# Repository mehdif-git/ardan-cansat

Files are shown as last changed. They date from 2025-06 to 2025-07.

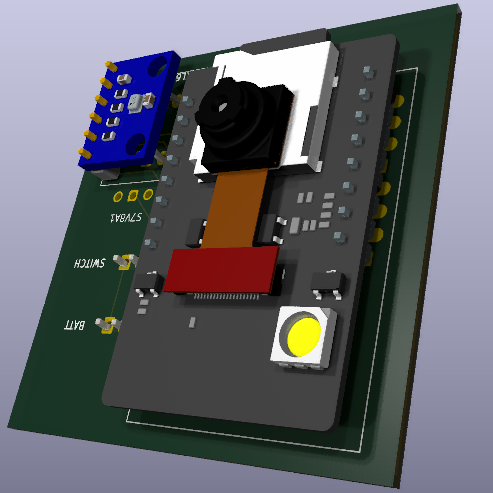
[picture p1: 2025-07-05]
Elec_Ardan/Pictures/Elec_Ardan.png

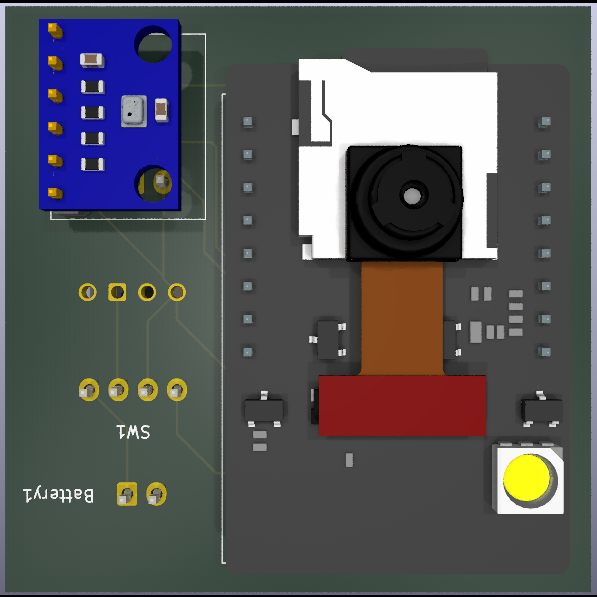
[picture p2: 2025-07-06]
Elec_Ardan/Pictures/Elec_Ardan_Front.png

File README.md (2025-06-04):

## SCALAR-VI CANSAT *Ardan*

## Description
Code and schematics of the cansat aboard SCALAR-VI made with students of the Jules Verne middleschool in Carcassone, FR.

## Installation
The ‘RadioHead’ library used to manage the LoRaWAN depends on “stdatomic”, we need to change the source code of ‘RadioHead’ to source the correct implementation for Arduino vs. ESP.

## Contributing
This work is common to the Supaero Space Section's Scalar project. Any project member is allowed to contribute.

## Authors and acknowledgment
Electronics has been made with the help of F. Topeza and C. Mopin-Rauschkolb.
CAD has been done entierly by D. Bessede

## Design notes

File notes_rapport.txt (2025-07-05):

\section{Électronique}

Liste des hacks faits :
\begin{itemize}
  \item Le connecteur de la batterie avait une polarisation opposée à celui du
    chargeur -> Utilisation de câbles Dupont pour résoudre le problème (ça marche,
    photos du problème, et de la tension au multimètre).
  \item La bibliothèque "RadioHead" utilisée pour gérer le LoRaWAN dépend de
    "stdatomic", on doit changer le code source de "RadioHead" pour en sourcer
    l'implémentation correcte pour Arduino  vs. ESP (montrer le code).
\begin{itemize}

\begin{figure}[H]
    \centering
    \frame{\includegraphics[width=0.8\textwidth]{images/Electronique/schematic.png}}
    \caption{Schéma de l'électronique à bord du cansat}
    \label{fig:enter-label}
\end{figure}

\begin{wrapfigure}{l}{0.25\textwidth}
    \frame{\includegraphics[width=0.95\linewidth]{images/Electronique/Test_elec_1.jpg}} 
    \caption{Tests électroniques}
    \label{fig:wrapfig}
\end{wrapfigure}

\noindent L'alimentation du cansat est assurée par une batterie LiPo d'une cellule de capacité de 550mAh. La tension nominale de la batterie Li-Po est de 3,7V. Pour assurer une sortie en 3,3V pour la majorité de l'électronique, un convertisseur \textit{buck-boost} (S7V8A) est utilisé. Ce dernier prends en entrée une tension entre 2,5 et 8V, largement au-delà de l'interval de 3 à 4,2V de la tension de la batterie.\\

\noindent Le buzzer est le seul composant électronique ne prenant pas en entrée une tension de 3,3V, l'architecture utilise un convertisseur \textit{boost} (XL6009) permettant d'élever la tension de 3,3V en 12V. Une diode (1N4007) est utilisée pour bloquer le retour de l'inductance du buzzer.\\

\noindent Le BMP280 communique avec l'ESP32 en I²C et le module LoRaWAN en UART.
Un pin de l'ESP32 est utilisé pour contrôler l'allumage du buzzer à travers un transistor (BC337-25) relié à une résistance pull-down de 100$k\Ohm$ pour assurer un état \textit{LOW} en général. Le buzzer est activé au moment de l'atterrissage du cansat.\\

\noindent 

\noindent Le courant maximal passant par le dispositif est de 245 milliampères :
\begin{itemize}
    \item  ESP32-CAM en prise d'image : pic de consommation à 200mA@3,3V
    \item  Consommation négligeable du BMP280 (2,7µA)
    \item  Module LoRa : 30mA@3,3V en émission
    \item  Buzzer : 15mA@12V en utilisation
\end{itemize}

La batterie permet donc un fonctionnement durant 2 heures.

\begin{figure}[!ht]
    \centering
    \begin{minipage}{0.3\textwidth}
        \centering
        \includegraphics[width=\textwidth]{images/Composants/BMP280.jpg}
        \caption{Module BMP280}
        \label{fig:bmp280}
    \end{minipage}
    \hfill
    \begin{minipage}{0.3\textwidth}
        \centering
        \includegraphics[width=\textwidth]{images/Composants/ESP32CAM.png}
        \caption{ESP32CAM}
        \label{fig:esp32cam}
    \end{minipage}
    \hfill
    \begin{minipage}{0.3\textwidth}
        \centering
        \includegraphics[width=\textwidth]{images/Composants/S7V8A.jpg}
        \caption{Module S7V8A}
        \label{fig:s7v8a}
    \end{minipage}

    \vspace{0.5cm} % Espace entre les deux rangées

    \begin{minipage}{0.3\textwidth}
        \centering
        \includegraphics[width=\textwidth]{images/Composants/DSN6009.jpg}
        \caption{XL6009}
        \label{fig:xl6009}
    \end{minipage}
    \hfill
    \begin{minipage}{0.3\textwidth}
        \centering
        \includegraphics[width=\textwidth]{images/Composants/LoRa WAN.png}
        \caption{Module LoRaWAN}
        \label{fig:lorawan}
    \end{minipage}
\end{figure}
\clearpage

\section{Logiciel}
\noindent Dans un but pédagogique, la programmation du microcontrôleur a été faite dans un système par blocs (similaire à \textit{Scratch}). Nous avons eu recours au \textit{BIPES Project} \cite{BIPES}, permettant d'utiliser des blocs pour programmer l'ESP32, en utilisant du MicroPython pour l'interprétation. Pour utiliser la caméra de l'ESP32-CAM avec MicroPython, il est nécessaire de compiler et installer sur la carte un nouveau firmware, possédant le module Python pour la caméra. Pour que ce firmware soit compatible avec BIPES, nous avons utilisé le travail de Sharil Tumin \cite{FIRM}. Enfin, le module BMP280 et le module LoRa WAN peuvent être utilisés directement par BIPES, à travers des bibliothèques Python s'installant à travers l'interface web.\bigskip

\noindent L'utilisation d'autant de fonctionnalités atteint cependant ses limites avec MicroPython et nous avons donc du recourir à un code en langage \textit{C++} pour éviter des instabilités.\\

\noindent Le code utilisé pour faire fonctionner le dispositif doit permettre de détecter la phase de décollage de la fusée ainsi que le largage du cansat. Cela est fait en utilisant le capteur de pression, qui permet de détecter l'altitude. Ainsi une forte baisse de pression indique une montée, et inversement. Lors de la phase de descente, la pression, la température, et une image prise par la caméra sont enregistrées périodiquement sur la carte SD, et les mesures de pression et température transmises au sol par le module LoRa.\\

\noindent Le code de vol doit composer avec une limitation notable de la plateforme ESP32-CAM : la saturation des bus du microcontrolleur. En effet entre la caméra et la carte SD, les entrées/sorties de l'ESP32 possèdent peu de disponibilités. Il a donc été choisi de tour à tour activer puis désactiver chaque composant, lors de chaque mesure, en sauvegardant d'abord en mémoire vive leur sortie, afin de réaliser les mesures et la captation d'images.

\noindent L'organisation du code est la suivante :
\begin{itemize}
\item Import des bibliothèques
\item Définition des variables globales
\item Définition des fonctions d'initialisation et de déinitialisation de chaque composant
\item Définition des fonctions utilitaires (écriture en carte SD et transmission par LoRa des mesures, détection de chute et d'atterrissage)
\item Définition des fonctions de captation des données et de mise en veille de l'ESP32
\item "void setup"
\item "void loop"
\end{itemize}

Le code de la boucle suit la temporalité de la mission : 
\begin{itemize}
\item Une première phase (pré-éjection) va périodiquement faire une estimation de l'altitude et de la vitesse du cansat. Si l'altitude commence à baisser assez rapidement (selon un seuil défini à partir des vitesses de chute attendues), le code passe à la boucle suivante.

\item Tant que le cansat n'est pas au sol des mesures de pression et de températures ainsi qu'une estimation de l'altitude vont périodiquement être réalisées, sauvegardées dans un fichier \textit{csv} stocké sur la carte µSD et émises en LoRaWAN. Une photo à l'instant de la mesure est aussi faite, elle est aussi stockée sur la carte SD. 

\item Une fois le cansat au sol (détection par altitude constante pendant quelques secondes), le pin contrôlant le transistor est mis en \textit{HIGH} et l'ESP32 est mis en sommeil profond.

\section{Télémétrie}

\noindent Le module LoRaWAN à bord du cansat transmettra les données jusqu'à un second module LoRaWAN au niveau de la station sol, connecté à un Arduino Uno connecté à un ordinateur, où nous pourrons suivre l'évolution en direct via la sortie série.\\

\noindent Les deux modules sont identiques, émettent et recoivent à 868MHz, fréquence libre en Union Européenne. Ils ont un gain de 20dBm pour une consommmation maximale de 20mW en émission.

Tests sur platine de prototypage :
\begin{itemize}
\item Test des régulateurs de tension : utilisation des potentiomètres pour régler
  leur sortie, mesures au multimètre pour s'assurer au premier ordre d'un bon
  output, puis à l'oscillo pour caractériser le bruit/les imperfections
\item Alimentation de l'ESP32-CAM seule, code initial de clignotage du flash pour
  s'assurer du bon fonctionnement.
\item Inclusion des périphériques 1 à 1 en commencant par un code de test propre
  à chaque périphérique puis un code les utilisant tous (ce code là deviens au
  final le code de vol)
\item Debug si nécessaire et vérification des tensions I/O au multimètre/à l'oscillo.
\end{itemize}

Insérer photos des montages.
Une fois le prototypage terminé, travail sur une PCB, selon les contraintes
mécaniques (détails Damien).
Conception PCB :
Schematic -> PCB (design préliminaire 2D) -> GrabCAD/SnapEDA -> Modèle 3D
(Insérer les docs)
Tests d'autonomie et de portée de la télem.

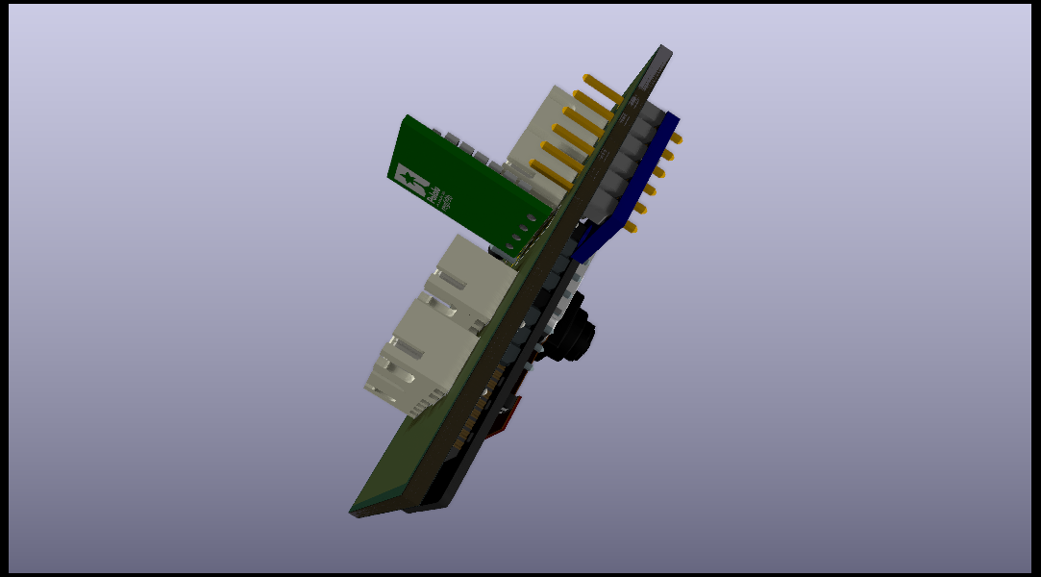
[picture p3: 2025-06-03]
Elec_Ardan/Pictures/Elec_Ardan_side.png

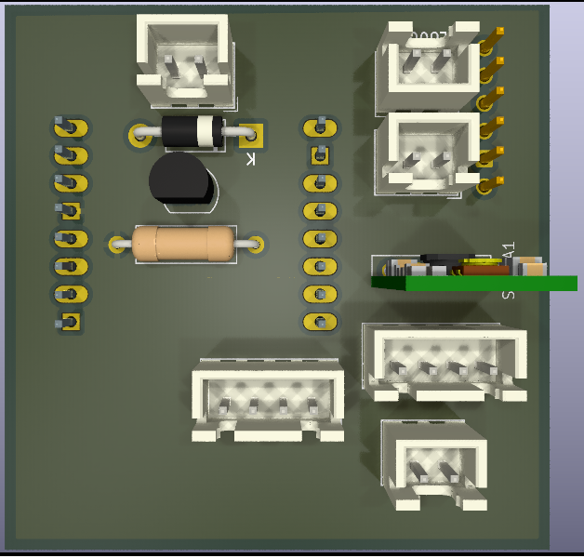
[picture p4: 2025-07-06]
Elec_Ardan/Pictures/Elec_Ardan_Back.png

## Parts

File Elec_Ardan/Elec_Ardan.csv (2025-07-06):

Reference | Value | Datasheet | Footprint | Qty | DNP
Battery1 | LiPo (3.7V, 550mAh) | ~ | Connector_JST:JST_XH_B2B-XH-A_1x02_P2.50mm_Vertical | 1
BMP280 | BMP280 | https://ae-bst.resource.bosch.com/media/_tech/media/datasheets/BST-BMP280-DS001.pdf | Footprints:BMP280 | 1
BZ1 | Buzzer | ~ | Connector_JST:JST_XH_B2B-XH-A_1x02_P2.50mm_Vertical | 1
Diode1 | 1N4007 | http://www.vishay.com/docs/88503/1n4001.pdf | Diode_THT:D_DO-41_SOD81_P10.16mm_Horizontal | 1
ESP32-CAM1 | ESP32-CAM |  | Footprints:ESP32-CAM | 1
Pull-Down1 | 100k | ~ | Resistor_THT:R_Axial_DIN0309_L9.0mm_D3.2mm_P12.70mm_Horizontal | 1
Q1 | BC337 | https://diotec.com/tl_files/diotec/files/pdf/datasheets/bc337.pdf | Package_TO_SOT_THT:TO-92_Inline | 1
RF96LoRa1 | UART,868MHz |  | Connector_JST:JST_XH_B4B-XH-A_1x04_P2.50mm_Vertical | 1
S7V8A1,XL6009 | ~ |  | -- valeurs mixées -- | 2
SW1 | SW_DIP_x02 | ~ | Connector_JST:JST_XH_B4B-XH-A_1x04_P2.50mm_Vertical | 1

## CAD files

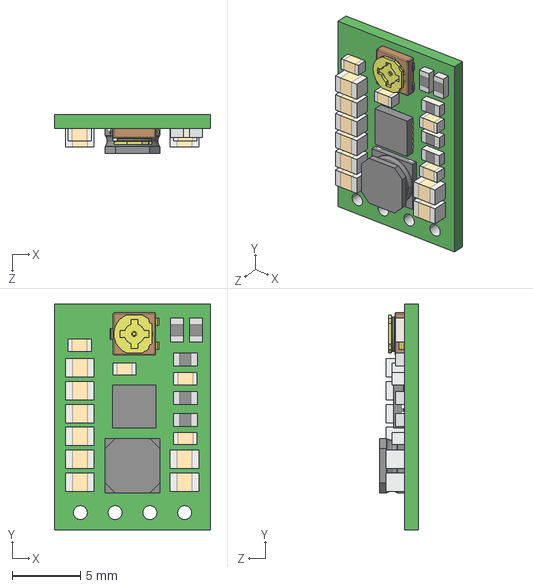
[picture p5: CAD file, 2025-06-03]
Elec_Ardan/STEP Files/S7V8A.step
11.4 x 16.5 x 2.82 mm

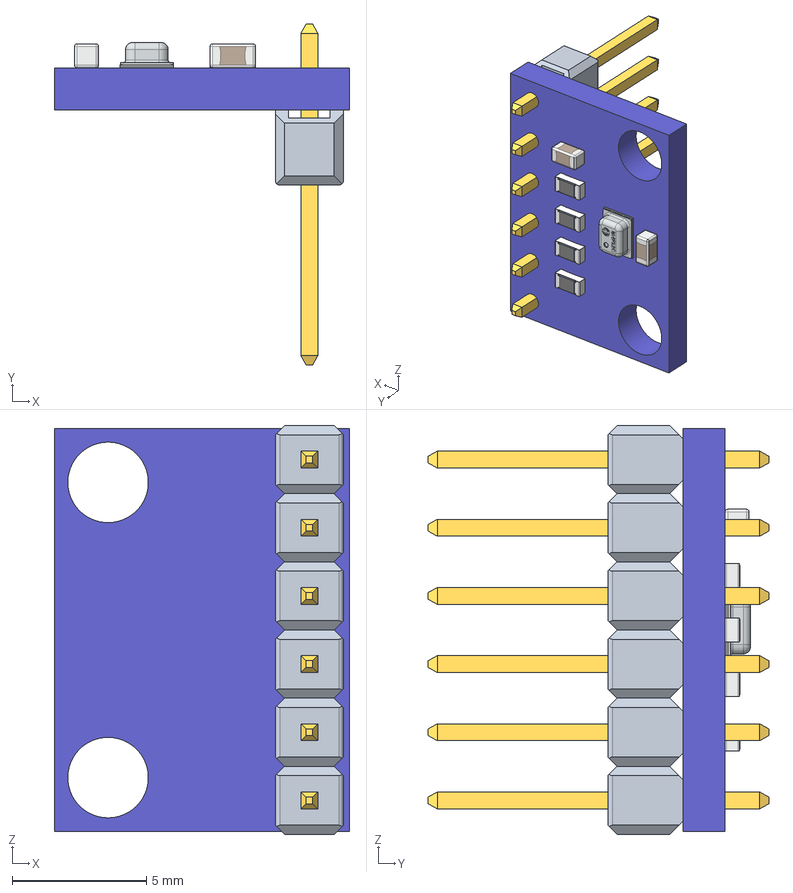
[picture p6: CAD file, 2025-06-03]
Elec_Ardan/STEP Files/BMP280.stp
11.0 x 12.7 x 15.2 mm

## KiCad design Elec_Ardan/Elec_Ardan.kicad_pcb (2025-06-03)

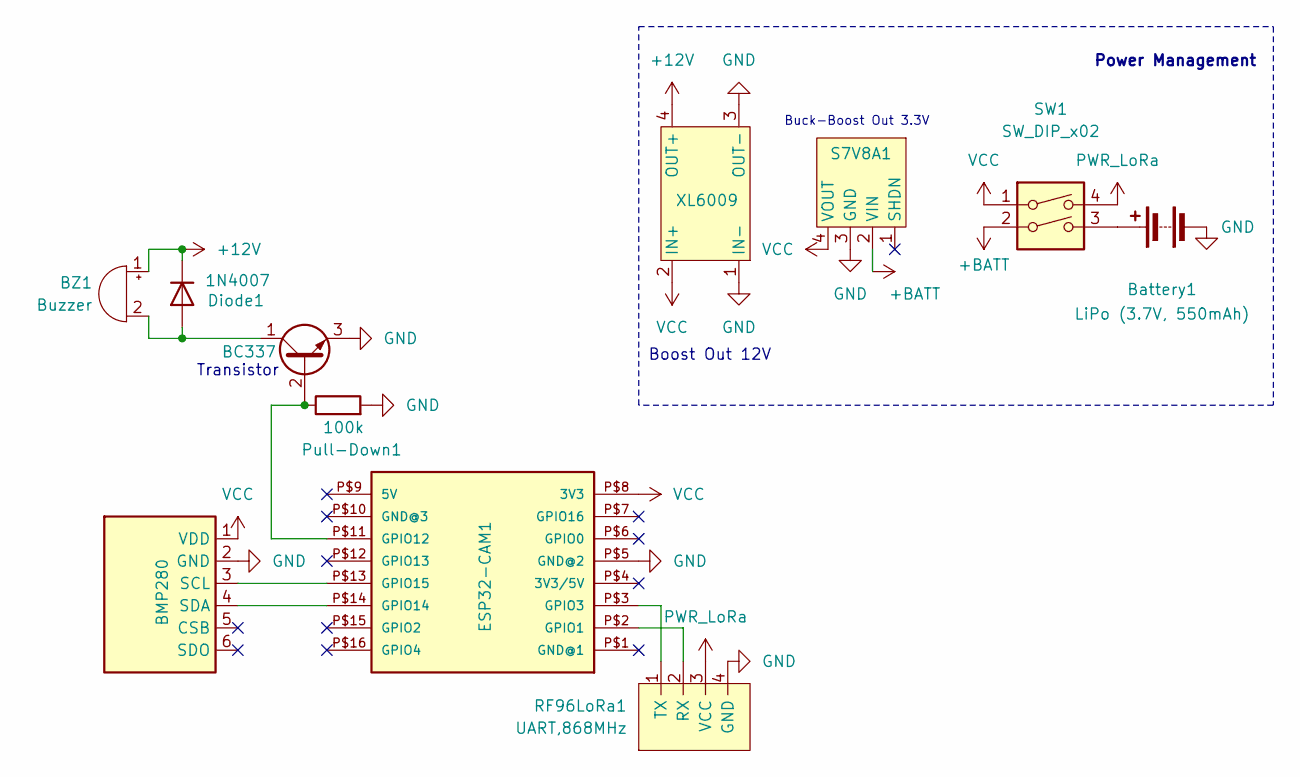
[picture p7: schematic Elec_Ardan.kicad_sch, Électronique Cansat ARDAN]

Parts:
BMP280: BMP280
BZ1: Buzzer; JST_XH_B2B-XH-A_1x02_P2.50mm_Vertical
Battery1: LiPo (3.7V, 550mAh); JST_XH_B2B-XH-A_1x02_P2.50mm_Vertical
Diode1: 1N4007; D_DO-41_SOD81_P10.16mm_Horizontal
ESP32-CAM1: ESP32-CAM
Pull-Down1: 100k; R_Axial_DIN0309_L9.0mm_D3.2mm_P12.70mm_Horizontal
Q1: BC337; TO-92_Inline
RF96LoRa1: UART,868MHz; JST_XH_B4B-XH-A_1x04_P2.50mm_Vertical
S7V8A1: S7V8A1
SW1: SW_DIP_x02; JST_XH_B4B-XH-A_1x04_P2.50mm_Vertical
XL6009: XL6009

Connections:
+12V: BZ1.1 (+), Diode1.1 (K), XL6009.4 (OUT+)
+BATT: S7V8A1.2 (VIN), SW1.2
GND: BMP280.2 (GND), Battery1.2 (-), ESP32-CAM1.P$5 (GND@2), Pull-Down1.2, Q1.3 (E), RF96LoRa1.4 (GND), S7V8A1.3 (GND), XL6009.1 (IN-), XL6009.3 (OUT-)
unnamed: BMP280.3 (SCL), ESP32-CAM1.P$13 (GPIO15)
unnamed: BMP280.4 (SDA), ESP32-CAM1.P$14 (GPIO14)
unnamed: BZ1.2 (-), Diode1.2 (A), Q1.1 (C)
unnamed: Battery1.1 (+), SW1.3
unnamed: ESP32-CAM1.P$2 (GPIO1), RF96LoRa1.2 (RX)
unnamed: ESP32-CAM1.P$3 (GPIO3), RF96LoRa1.1 (TX)
unnamed: ESP32-CAM1.P$11 (GPIO12), Pull-Down1.1, Q1.2 (B)
PWR_LoRa: RF96LoRa1.3 (VCC), SW1.4
VCC: BMP280.1 (VDD), ESP32-CAM1.P$8 (3V3), S7V8A1.4 (VOUT), SW1.1, XL6009.2 (IN+)

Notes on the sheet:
Power Management
Buck-Boost Out 3.3V
Boost Out 12V
Transistor

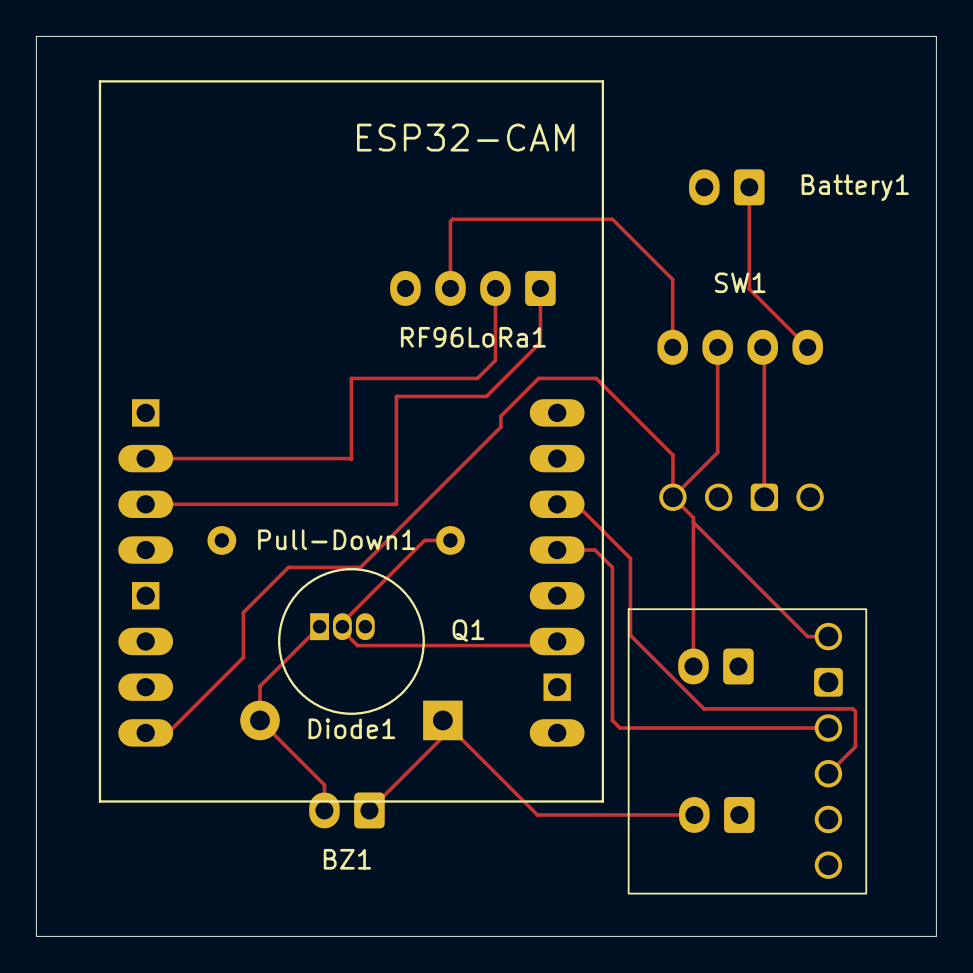
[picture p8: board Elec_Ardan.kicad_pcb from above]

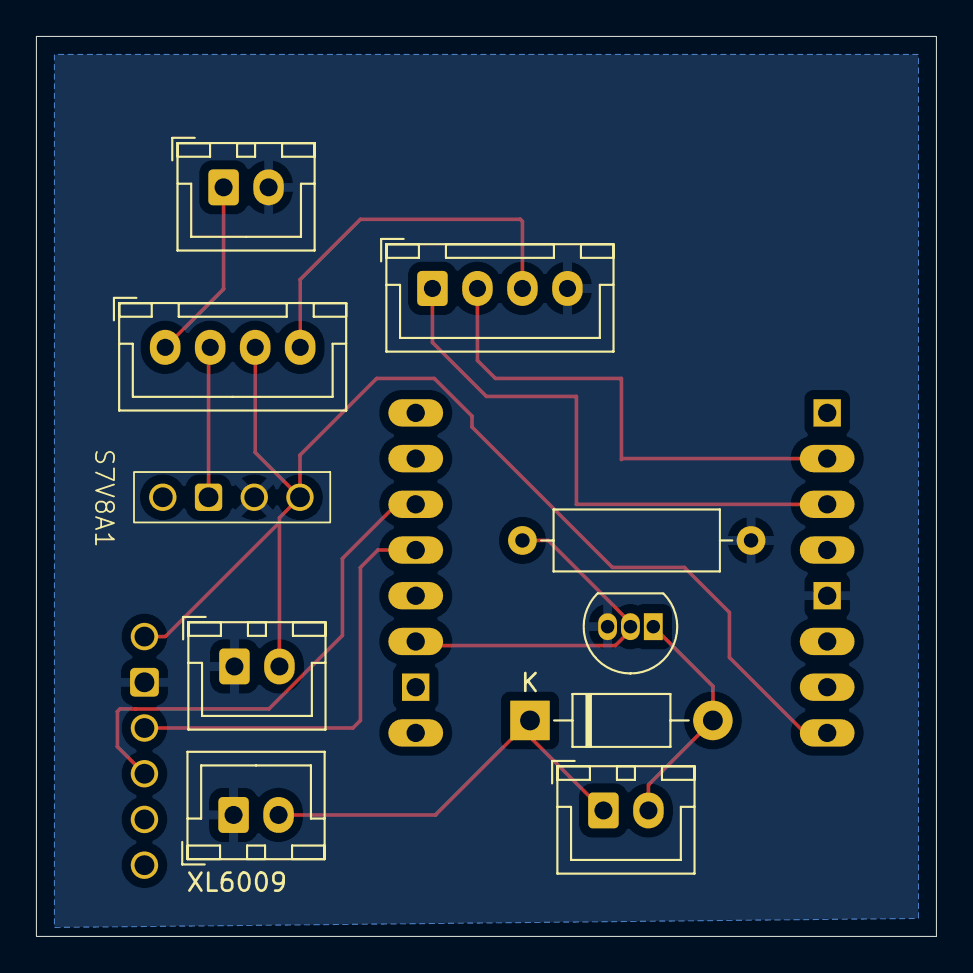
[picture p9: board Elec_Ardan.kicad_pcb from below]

Board: 2 copper layers, 50.0 x 50.0 mm, 11 parts (9 on the bottom side), 12 nets.

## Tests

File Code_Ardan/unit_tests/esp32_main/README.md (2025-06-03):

# ESP32_BMP280_Test

Ce projet permet de tester le module BMP 280 sur une carte ESP32. Le code principal lit les données de température et de pression du capteur et les affiche sur le moniteur série.

## Matériel requis

- Carte ESP32
- Module BMP 280
- Câbles de connexion

## Connexions

| BMP 280 Pin | ESP32 Pin |
|---|---|
| VCC | 3.3V |
| GND | GND |
| SDA | GPIO 21  |
| SCL | GPIO 22  |

## Installation des bibliothèques

Pour utiliser le module BMP 280, vous devez installer la bibliothèque Adafruit BMP280. Vous pouvez le faire via le gestionnaire de bibliothèques de l'IDE Arduino :

1. Ouvrez l'IDE Arduino.
2. Allez dans `Sketch` > `Include Library` > `Manage Libraries...`
3. Recherchez "Adafruit BMP280" et installez la bibliothèque.

## Exécution du code

1. Téléversez le code contenu dans `ESP32_BMP280_Test.ino` sur votre carte ESP32.
2. Ouvrez le moniteur série (à 115200 bauds) pour voir les données de température et de pression affichées.

## Remarques

Assurez-vous que votre module BMP 280 est correctement connecté à l'ESP32 avant de téléverser le code. Si vous rencontrez des problèmes, vérifiez les connexions et assurez-vous que la bibliothèque est correctement installée.

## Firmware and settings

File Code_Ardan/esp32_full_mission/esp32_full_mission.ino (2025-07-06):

/*
 * Ardan CanSat Main Code
 */

 #include <BMP280.h>
 #include "esp_camera.h"
 #include "FS.h"
 #include "SD_MMC.h"
 #include "Wire.h"
 #include <EEPROM.h>
 #include <RH_RF95.h>
 #include "esp_sleep.h"
 
 // === CONFIGURATION DES BROCHES ===
 #define I2C_SDA           14
 #define I2C_SCL           15
 #define TRANSISTOR_PIN    12
 #define EEPROM_SIZE       2
 
 // Configuration caméra ESP-EYE
 #define CAMERA_MODEL_ESP_EYE
 #define PWDN_GPIO_NUM     32
 #define RESET_GPIO_NUM    -1
 #define XCLK_GPIO_NUM      0
 #define SIOD_GPIO_NUM     26
 #define SIOC_GPIO_NUM     27
 #define Y9_GPIO_NUM       35
 #define Y8_GPIO_NUM       34
 #define Y7_GPIO_NUM       39
 #define Y6_GPIO_NUM       36
 #define Y5_GPIO_NUM       21
 #define Y4_GPIO_NUM       19
 #define Y3_GPIO_NUM       18
 #define Y2_GPIO_NUM        5
 #define VSYNC_GPIO_NUM    25
 #define HREF_GPIO_NUM     23
 #define PCLK_GPIO_NUM     22
 
 // === PARAMÈTRES DE DÉTECTION ===
 const int BUFFER_SIZE = 5;              // Taille du buffer de lissage
 const float FALL_THRESHOLD = -0.5;      // Seuil de vitesse pour détecter la chute (m/s)
 const float GROUND_THRESHOLD = 0.05;    // Seuil de vitesse pour détecter l'arrêt (m/s)
 const float LAUNCH_THRESHOLD = 2.0;     // Seuil de vitesse pour détecter le lancement (m/s)
 const float DT = 0.5;                   // Pas de temps en secondes
 const float MIN_FALL_DURATION = 10;    // Durée minimale de chute (secondes)
 const float MIN_LAUNCH_DURATION = 2;   // Durée minimale de lancement (secondes)
 const float STATIONARY_TIME_REQ = 10;  // Temps requis pour confirmer l'arrêt (secondes)
 
 // === VARIABLES GLOBALES ===
 int pictureNumber = 0;
 BMP280 bmp = BMP280(0x76);
 File dataFile;
 RH_RF95<HardwareSerial> rf95(Serial);
 
 // Variables de détection de mission
 float altitudeBuffer[BUFFER_SIZE];
 int bufferIndex = 0;
 float previousSmoothed = 0.0;
 float launchTime = 0.0;
 bool bufferFilled = false;
 float fallTime = 0.0;
 float stationaryTime = 0.0;
 bool launchDetected = false;
 bool fallDetected = false;
 bool onGround = false;
 
 // === FONCTIONS D'INITIALISATION ===
 
 void initCamera() {
   camera_config_t config;
   config.ledc_channel = LEDC_CHANNEL_0;
   config.ledc_timer = LEDC_TIMER_0;
   config.pin_d0 = Y2_GPIO_NUM;
   config.pin_d1 = Y3_GPIO_NUM;
   config.pin_d2 = Y4_GPIO_NUM;
   config.pin_d3 = Y5_GPIO_NUM;
   config.pin_d4 = Y6_GPIO_NUM;
   config.pin_d5 = Y7_GPIO_NUM;
   config.pin_d6 = Y8_GPIO_NUM;
   config.pin_d7 = Y9_GPIO_NUM;
   config.pin_xclk = XCLK_GPIO_NUM;
   config.pin_pclk = PCLK_GPIO_NUM;
   config.pin_vsync = VSYNC_GPIO_NUM;
   config.pin_href = HREF_GPIO_NUM;
   config.pin_sccb_sda = SIOD_GPIO_NUM;
   config.pin_sccb_scl = SIOC_GPIO_NUM;
   config.pin_pwdn = PWDN_GPIO_NUM;
   config.pin_reset = RESET_GPIO_NUM;
   config.xclk_freq_hz = 20000000;
   config.pixel_format = PIXFORMAT_JPEG;
   
   // Configuration selon la PSRAM disponible
   if (psramFound()) {
     config.frame_size = FRAMESIZE_SVGA;
     config.jpeg_quality = 5;
     config.fb_count = 1;
   } else {
     config.frame_size = FRAMESIZE_VGA; // Réduit pour économiser la mémoire
     config.jpeg_quality = 8;
     config.fb_count = 1;
   }
   
   esp_camera_init(&config);
 }
 
 void initBMP280() {
   Wire.setPins(I2C_SDA, I2C_SCL);
   Wire.begin();
   bmp.begin();
   delay(200);
 }
 
 void initSDCard() {
   SD_MMC.begin("/sdcard",true);
   createDataFileIfNotExist();
 }
 
 void initLORA() {
   rf95.init();
   rf95.setTxPower(23, false);
   rf95.setFrequency(868.125);
 }
 
 // === FONCTIONS DE DÉSINITIALISATION ===
 
 void deinitCamera() {
   esp_camera_deinit();
 }
 
 void deinitBMP280() {
   bmp.reset();
   Wire.end();
 }
 
 void deinitSDCard() {
   dataFile.close();
   SD_MMC.end();
 }
 
 void deinitLORA() {
   rf95.setModeIdle();
   rf95.sleep();
 }
 
 // === FONCTIONS UTILITAIRES ===
 
 void createDataFileIfNotExist() {
   if (!SD_MMC.exists("/bmp280_data.csv")) {
     dataFile = SD_MMC.open("/bmp280_data.csv", FILE_WRITE);
     if (dataFile) {
       dataFile.println("Timestamp,Temperature (C),Pressure (hPa),Altitude (m)");
       dataFile.close();
     }
   }
 }
 
 void saveDataToSD(float temperature, float pressure, float altitude) {
   dataFile = SD_MMC.open("/bmp280_data.csv", FILE_APPEND);
   if (dataFile) {
     dataFile.print(millis() / 1000.0);
     dataFile.print(",");
     dataFile.print(temperature);
     dataFile.print(",");
     dataFile.print(pressure);
     dataFile.print(",");
     dataFile.println(altitude);
     dataFile.close(); // Fermer immédiatement pour économiser l'énergie
   }
 }
 
 void takePicture() {
   camera_fb_t *fb = esp_camera_fb_get();
   if (!fb) return;
   
   EEPROM.begin(EEPROM_SIZE);
   pictureNumber = EEPROM.read(0) + 1;
   
   String path = "/picture" + String(pictureNumber) + ".jpg";
   File file = SD_MMC.open(path.c_str(), FILE_WRITE);
   if (file) {
     file.write(fb->buf, fb->len);
     file.close();
     
     EEPROM.write(0, pictureNumber);
     EEPROM.commit();
   }
   
   esp_camera_fb_return(fb);
 }
 
 void sendData(float temperature, uint32_t pressure, int16_t altitude) {
   char buffer[64];
   int len = sprintf(buffer,"%f %u %hd ", temperature, pressure, altitude);
   rf95.send((uint8_t*)buffer, len);
   rf95.waitPacketSent();
 }
 
 // === FONCTIONS DE DÉTECTION ===
 
 float getSmoothedAltitude(float rawAltitude) {
   // Mise à jour du buffer circulaire
   altitudeBuffer[bufferIndex] = rawAltitude;
   bufferIndex = (bufferIndex + 1) % BUFFER_SIZE;
   if (bufferIndex == 0) bufferFilled = true;
   
   // Calcul de la moyenne lissée
   float smoothedAltitude = 0.0;
   int count = bufferFilled ? BUFFER_SIZE : bufferIndex;
   for (int i = 0; i < count; i++) {
     smoothedAltitude += altitudeBuffer[i];
   }
   return smoothedAltitude / count;
 }
 
 void detectLaunch() {
  float rawAltitude = bmp.calAltitude(bmp.getPressure(), 1013.25);
  float smoothedAltitude = getSmoothedAltitude(rawAltitude);
  
  // Calcul de la vitesse (dérivée première)
  float velocity = (smoothedAltitude - previousSmoothed) / DT;
  previousSmoothed = smoothedAltitude;
  
  // Détection de lancement (vitesse ascendante soutenue)
  if (velocity > LAUNCH_THRESHOLD) {
    launchTime += DT;
    if (launchTime >= MIN_LAUNCH_DURATION) {
      launchDetected = true;
    }
  } else {
    launchTime = 0;
  }
}

 void detectFall() {
   float rawAltitude = bmp.calAltitude(bmp.getPressure(), 1013.25);
   float smoothedAltitude = getSmoothedAltitude(rawAltitude);
   
   // Calcul de la vitesse (dérivée première)
   float velocity = (smoothedAltitude - previousSmoothed) / DT;
   previousSmoothed = smoothedAltitude;
   
   // Détection de chute
   if (velocity < FALL_THRESHOLD) {
     fallTime += DT;
     if (fallTime >= MIN_FALL_DURATION) {
       fallDetected = true;
     }
   } else {
     fallTime = 0;
   }
 }
 
 void detectGroundContact() {
   initBMP280();
   float rawAltitude = bmp.calAltitude(bmp.getPressure(), 1013.25);
   deinitBMP280();
   float smoothedAltitude = getSmoothedAltitude(rawAltitude);
   
   // Calcul de la vitesse
   float velocity = (smoothedAltitude - previousSmoothed) / DT;
   previousSmoothed = smoothedAltitude;
   
   // Détection d'arrêt au sol
   if (abs(velocity) < GROUND_THRESHOLD) {
     stationaryTime += DT;
     if (stationaryTime >= STATIONARY_TIME_REQ) {
       onGround = true;
     }
   } else {
     stationaryTime = 0;
   }
 }
 
 // === MISSION PRINCIPALE ===
 
 void executeMainMission() {
   // Lecture des données du capteur
   initBMP280();
   float temperature = bmp.getTemperature();
   uint32_t pressure = bmp.getPressure();
   int16_t altitude = bmp.calAltitude(pressure, 1013.25);
   deinitBMP280();

   // Sauvegarde des données
   initSDCard();
   saveDataToSD(temperature, pressure, altitude);
   
   // Prise de photo
   initCamera();
   takePicture();
   deinitCamera();
   deinitSDCard();

   // Transmission LoRa
   sendData(temperature, pressure, altitude);
 }
 
 void enterDeepSleepWithTransistor() {
   // Désactivation de tous les périphériques
   deinitLORA();

   // Configuration du transistor en HIGH avant le sommeil
   digitalWrite(TRANSISTOR_PIN, HIGH);
   
   // Configuration pour maintenir l'état de la broche pendant le sommeil
   gpio_hold_en((gpio_num_t)TRANSISTOR_PIN);
   gpio_deep_sleep_hold_en();
   
   // Entrée en sommeil profond (réveil uniquement par reset)
   esp_deep_sleep_start();
 }
 
 // === PROGRAMME PRINCIPAL ===
 
 void setup() {
  // Making sure pin 12 is not latched on (for restarts only)
  pinMode(TRANSISTOR_PIN, OUTPUT);
  gpio_hold_dis((gpio_num_t)TRANSISTOR_PIN);
  gpio_deep_sleep_hold_dis();
  digitalWrite(TRANSISTOR_PIN, HIGH);
  delay(500);
  digitalWrite(TRANSISTOR_PIN, LOW);
  initBMP280();
 }
 
 void loop() {
   while(!launchDetected){
    detectLaunch();
   }
   // Phase 1: Détection de chute
   while (!fallDetected) {
    detectFall();
   }
   deinitBMP280();
   // Phase 2: Mission principale (acquisition et transmission)
   initLORA();
   delay(200);
   uint8_t startMessage[] = "Started!\n"; // Messages start with 'm'
   rf95.send(startMessage, sizeof(startMessage));
   rf95.waitPacketSent();

   while (!onGround) {
     executeMainMission();
     detectGroundContact();
   }
   uint8_t endMessage[] = "Landed!\n"; 
   rf95.send(endMessage, sizeof(endMessage));
   rf95.waitPacketSent();
   
   // Phase 3: Mode récupération avec optimisation énergétique
   enterDeepSleepWithTransistor();
 }

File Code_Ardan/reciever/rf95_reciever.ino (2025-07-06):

// rf95_server.pde
// -*- mode: C++ -*-

#include <RH_RF95.h>
#include <SoftwareSerial.h>
SoftwareSerial SSerial(10, 11); // RX, TX
#define COMSerial SSerial
#define ShowSerial Serial

RH_RF95<SoftwareSerial> rf95(COMSerial);

int led = 13;

void setup() {
    ShowSerial.begin(115200);
    ShowSerial.println("Reciever STARTED.");

    pinMode(led, OUTPUT);

    if (!rf95.init()) {
        ShowSerial.println("init failed");
        while (1);
    }
    // Defaults after init are 868.0MHz, 13dBm, Bw = 125 kHz, Cr = 4/5, Sf = 128chips/symbol, CRC on

    // The default transmitter power is 13dBm, using PA_BOOST.
    // If you are using RFM95/96/97/98 modules which uses the PA_BOOST transmitter pin, then
    // you can set transmitter powers from 5 to 23 dBm:
    //rf95.setTxPower(13, false);

    rf95.setFrequency(868.125);
}

void loop() {
    if (rf95.available()) {
        uint8_t buf[64];
        uint8_t len = sizeof(buf);
        if(rf95.recv(buf, &len)){
            digitalWrite(led, HIGH);
            char message[64];
            char temperature[16];
            char pressure[16];
            char altitude[16];
            if(sscanf((char*)buf,"%s %s %s ",temperature,pressure,altitude)){
                ShowSerial.println(temperature);
                ShowSerial.println(pressure);
                ShowSerial.println(altitude);
            } else{
                sscanf((char*)buf, "%s\n", message);
                ShowSerial.println(message);
            }
            digitalWrite(led, LOW);
        }
    }
}

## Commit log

2025-03-03 Arduino code.
2025-06-03 Version du projet 3 juin 2025.
    [BMP280.stp, Elec_Ardan.kicad_pcb, Elec_Ardan.kicad_sch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]
2025-06-03 Ajout du fichier STEP de la carte entière
    [Elec_Ardan.kicad_pcb]
2025-06-03 Ajout de notes pour le rapport de la RCE 3.
2025-07-06 Unit tests
    [Elec_Ardan.csv]
